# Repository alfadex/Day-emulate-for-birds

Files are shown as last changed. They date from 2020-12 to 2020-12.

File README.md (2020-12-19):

# Day-light-emulate-for-birds

Operation of the project
https://github.com/alfadex/Day-emulate-for-birds/wiki

Ζero cross detection
https://alfadex.com/2014/02/dimming-230v-ac-with-arduino-2/

Bird timer Switch v.1
https://alfadex.com/2015/03/bird-timer-switch/

Bird timer Switch v.2
https://alfadex.com/2015/03/bird-timer-switch-v-2/

Code for this project refer to v.2

video
https://youtu.be/kFFZ-1XAeRA

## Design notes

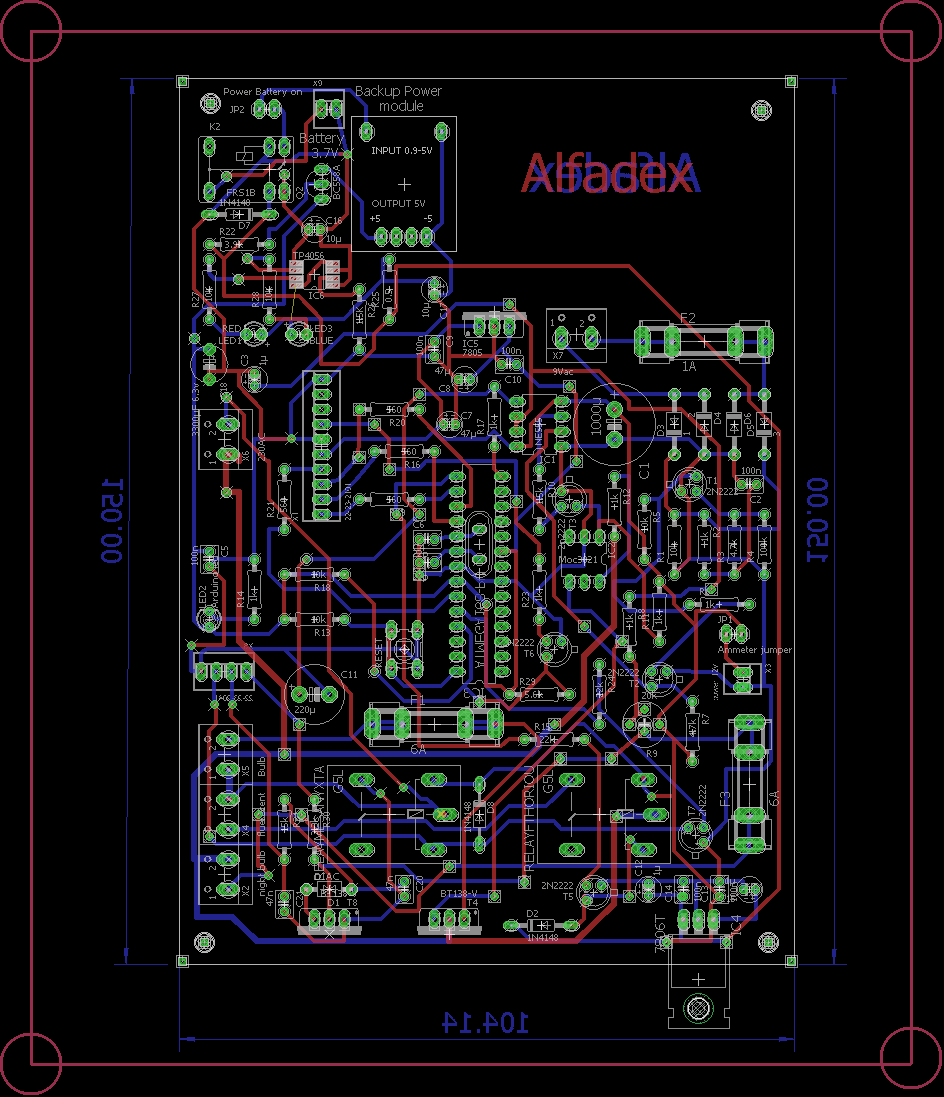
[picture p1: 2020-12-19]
Schematic-board files/Board.png

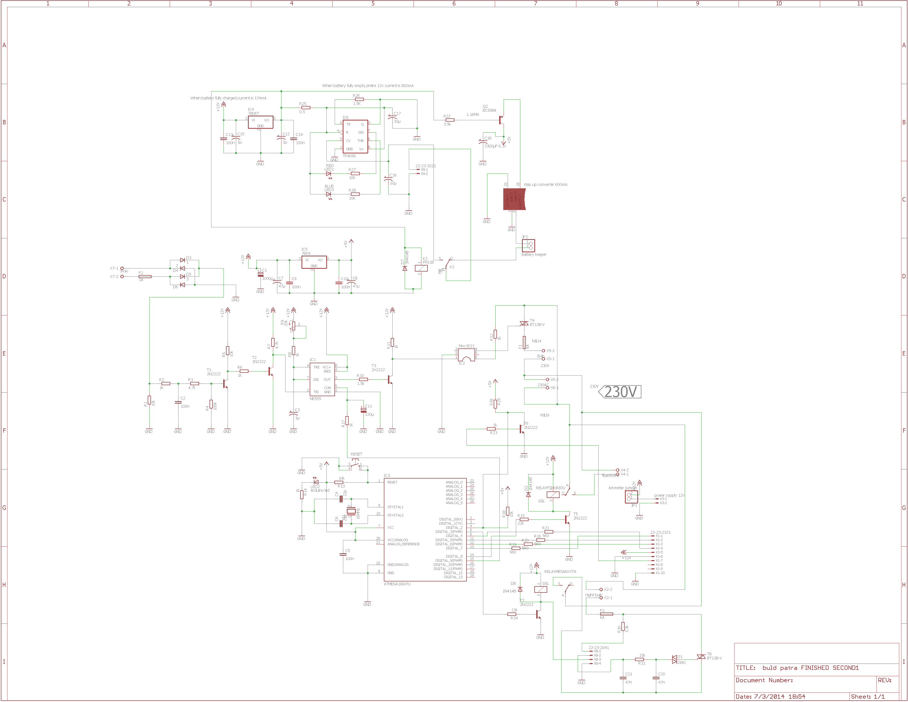
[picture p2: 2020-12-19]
Schematic-board files/schematic.png

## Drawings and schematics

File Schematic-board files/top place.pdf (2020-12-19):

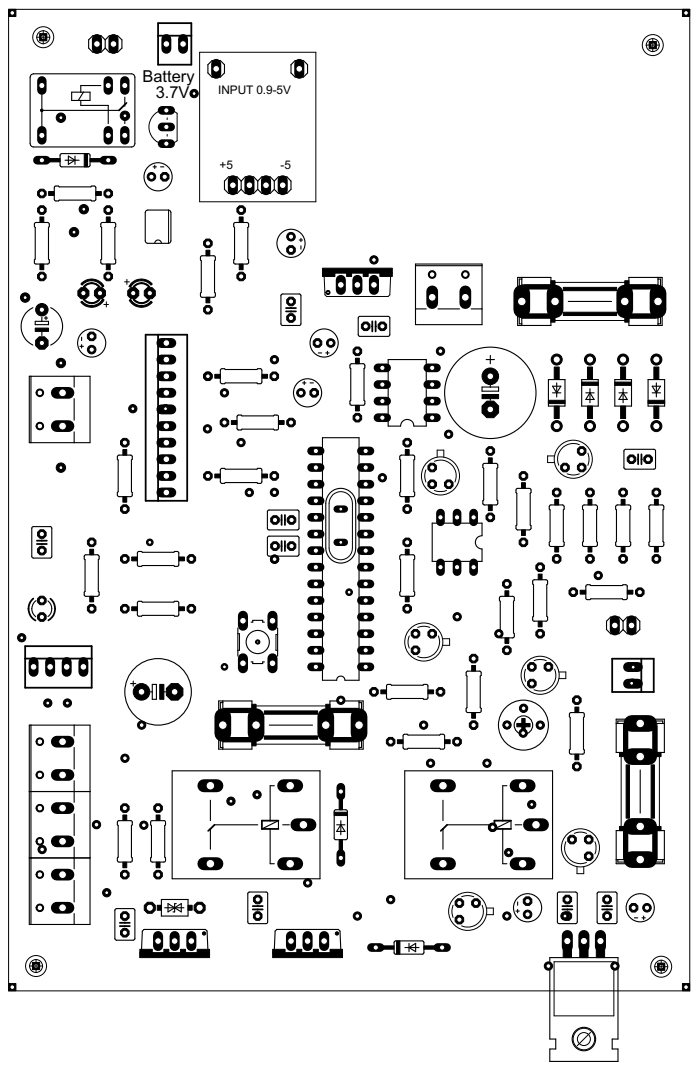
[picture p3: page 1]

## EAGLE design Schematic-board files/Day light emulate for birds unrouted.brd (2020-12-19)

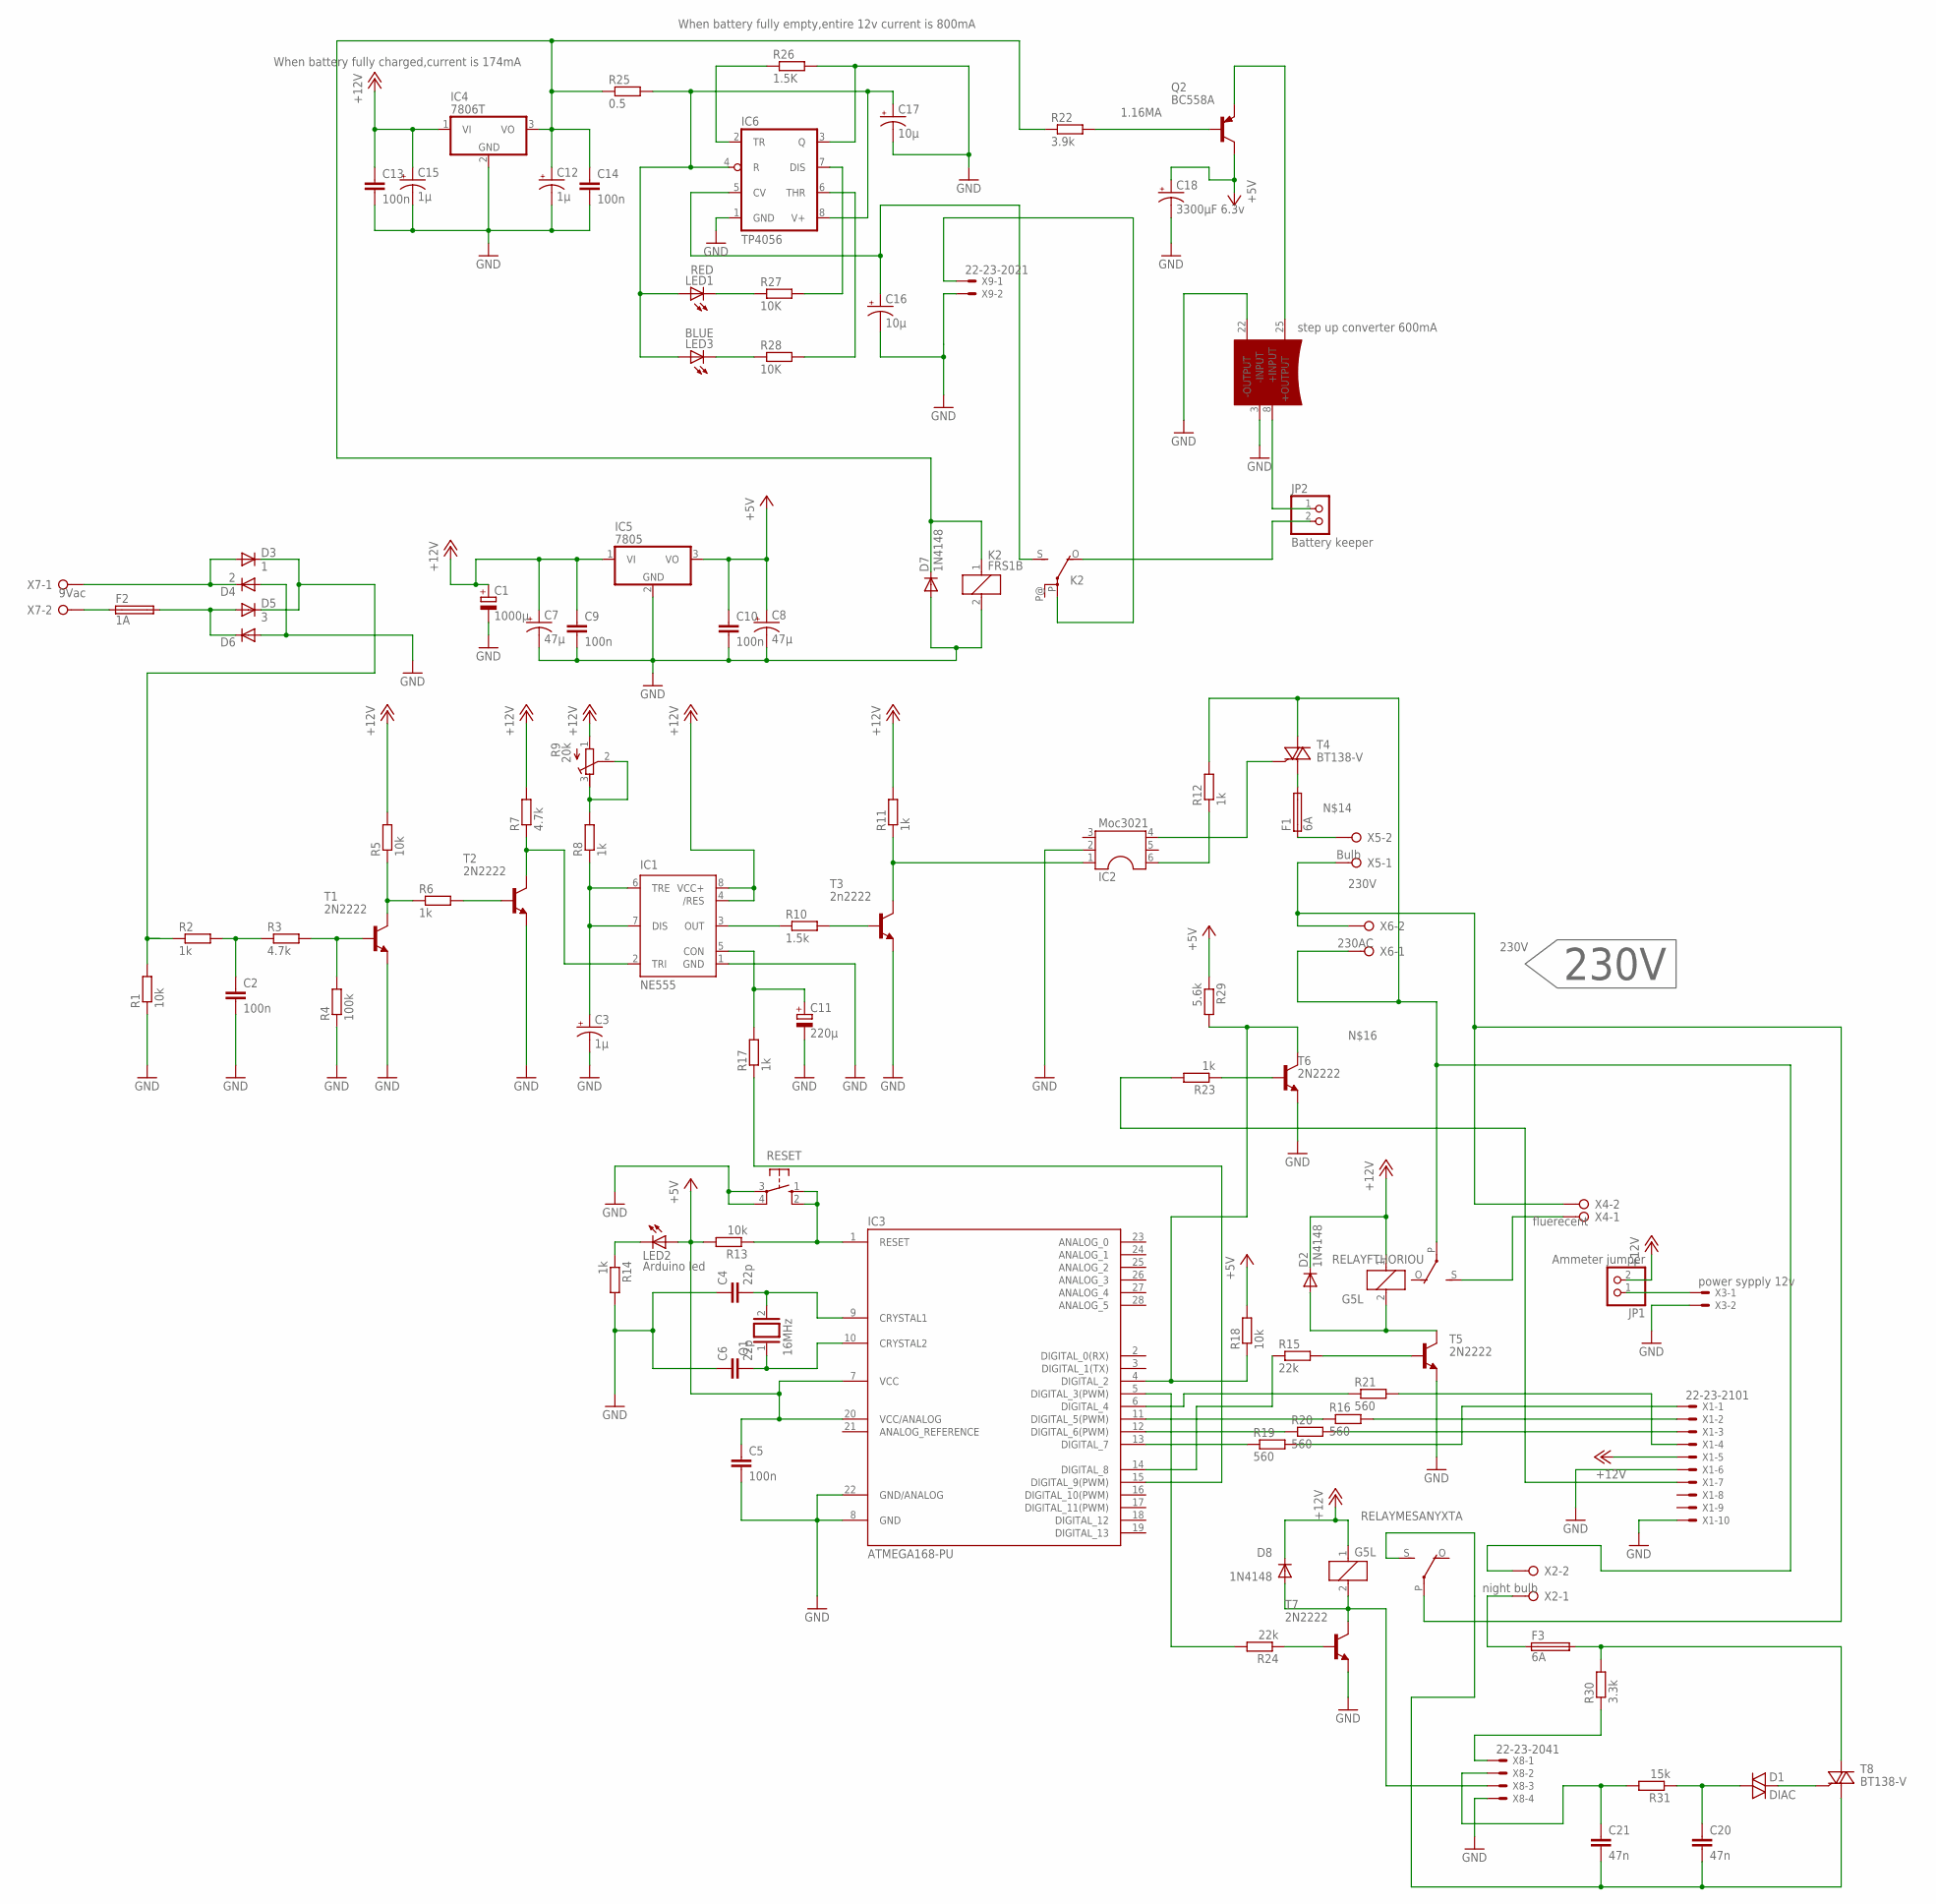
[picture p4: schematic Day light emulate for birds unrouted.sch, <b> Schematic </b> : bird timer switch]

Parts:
C1: 1000μ; E5-13
C2, C5, C9, C10, C13, C14: 100n; C025-030X050
C3, C12, C15: 1μ; E2-4
C4, C6: 22p; C025-030X050
C7, C8: 47μ; E2-4
C11: 220μ; E5-10,5
C16, C17: 10μ; E2-4
C18: 3300μF 6.3v; E5-6
C20, C21: 47n; C025-030X050
D1: DIAC; GT32
D2, D7, D8: 1N4148; DO35-10
D3: 1; DO41-10
D4: 2; DO41-10
D5: 3; DO41-10
D6: 1N4004; DO41-10
F1, F3: 6A; SHK20L
F2: 1A; SHK20L
IC1: NE555; DIL-08
IC2: Moc3021; DIL06
IC3: ATMEGA168-PU; DIL28-3
IC4: 7806T; TO220H
IC5: 7805; TO220V
IC6: TP4056; SO08
JP1: Ammeter jumper; 1X02
JP2: Battery keeper; 1X02
K2: FRS1B
LED1: RED; LED3MM
LED2: Arduino led; LED3MM
LED3: BLUE; LED3MM
Q1: 16MHz; QS
Q2: BC558A; TO92-EBC
R1, R5, R13, R18: 10k; 0207/10
R2, R6, R8, R11, R12, R14, R17, R23: 1k; 0207/10
R3, R7: 4.7k; 0207/10
R4: 100k; 0207/10
R9: 20k; RTRIM3339P
R10: 1.5k; 0207/10
R15, R24: 22k; 0207/10
R16, R19, R20, R21: 560; 0207/10
R22: 3.9k; 0207/10
R25: 0.5; 0207/10
R26: 1.5K; 0207/10
R27, R28: 10K; 0207/10
R29: 5.6k; 0207/10
R30: 3.3k; 0207/10
R31: 15k; 0207/10
RELAYFTHORIOU: G5L; G5LE
RELAYMESANYXTA: G5L; G5LE
RESET: 10-XX; B3F-10XX
STEPUP1: steup converter 600mA; STEPUP_CONVERTER_600MA
T1, T2, T5, T6, T7: 2N2222; TO18
T3: 2n2222; TO18
T4, T8: BT138-V; TO220BV
X1: 22-23-2101
X2: night bulb; W237-132
X3: power sypply 12v; 22-23-2021
X4: fluerecent; W237-132
X5: Bulb; W237-132
X6: 230AC; W237-132
X7: 9Vac; W237-132
X8: 22-23-2041
X9: 22-23-2021

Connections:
1.16MA: Q2.B, R22.2
230V: RELAYMESANYXTA.P, X4.2, X5.1, X6.2
+5V: C5.1, C8.+, C10.1, C18.+, IC3.7 (VCC), IC3.20 (VCC/ANALOG), IC5.3 (VO), LED2.A, Q2.C, R13.2, R18.2, R29.1
+12V: C1.+, C7.+, C9.1, C13.1, C15.+, D2.C, D8.C, IC1.4 (/RES), IC1.8 (VCC+), IC4.1 (VI), IC5.1 (VI), JP1.2, R5.2, R7.2, R9.1 (E), R11.2, RELAYFTHORIOU.1, RELAYMESANYXTA.1, X1.5
GND: C1.-, C2.2, C3.-, C4.1, C5.2, C6.1, C7.-, C8.-, C9.2, C10.2, C11.-, C12.-, C13.2, C14.2, C15.-, C16.-, C17.-, C18.-, D4.A, D6.A, D7.A, IC1.1 (GND), IC2.2, IC3.8 (GND), IC3.22 (GND/ANALOG), IC4.2 (GND), IC5.2 (GND), IC6.1 (GND), IC6.3 (Q), K2.2, R1.1, R4.1, R14.2, R26.2, RESET.3, RESET.4 (P1), STEPUP1.3 (-INPUT), STEPUP1.22 (-OUTPUT), T1.1 (E), T2.1 (E), T3.1 (E), T5.1 (E), T6.1 (E), T7.1 (E), X1.6, X1.10, X3.2, X8.4, X9.2
MORNING: R19.2, X1.1
unnamed: IC3.11 (DIGITAL_5(PWM)), R16.1
unnamed: C2.1, R2.2, R3.1
unnamed: R3.2, R4.2, T1.2 (B)
unnamed: R5.1, R6.1, T1.3 (C)
unnamed: R6.2, T2.2 (B)
unnamed: IC1.2 (TRI), R7.1, T2.3 (C)
unnamed: R8.2, R9.2 (S), R9.3 (A)
unnamed: IC1.3 (OUT), R10.1
unnamed: C3.+, IC1.6 (TRE), IC1.7 (DIS), R8.1
unnamed: R10.2, T3.2 (B)
unnamed: IC2.1, R11.1, T3.3 (C)
unnamed: IC2.6, R12.1
unnamed: IC2.4, T4.G
unnamed: F1.1A (1), X5.2
unnamed: JP2.1, STEPUP1.8 (+INPUT)
unnamed: R12.2, RELAYFTHORIOU.P, T4.T2 (A2), X2.2, X6.1
unnamed: F2.1A (1), X7.2
unnamed: IC3.1 (RESET), R13.1, RESET.1 (S), RESET.2 (S1)
unnamed: LED2.K (C), R14.1
unnamed: D1.2, T8.G
unnamed: C6.2, IC3.10 (CRYSTAL2), Q1.1
unnamed: C4.2, IC3.9 (CRYSTAL1), Q1.2
unnamed: IC3.14 (DIGITAL_8), R15.1
unnamed: R15.2, T5.2 (B)
unnamed: D2.A, RELAYFTHORIOU.2, T5.3 (C)
unnamed: IC3.13 (DIGITAL_7), R19.1
unnamed: C11.+, IC1.5 (CON), R17.2
unnamed: R16.2, X1.2
unnamed: IC3.15 (DIGITAL_9(PWM)), R17.1
unnamed: IC3.6 (DIGITAL_4), R21.1
unnamed: R21.2, X1.4
unnamed: RELAYFTHORIOU.S, X4.1
unnamed: IC3.12 (DIGITAL_6(PWM)), R20.1
unnamed: D3.A, D4.C, X7.1
unnamed: D5.A, D6.C, F2.2A (2)
unnamed: D3.C, D5.C, R1.2, R2.1
unnamed: R20.2, X1.3
unnamed: K2.P, X9.1
unnamed: JP2.2, K2.O
unnamed: C12.+, C14.1, D7.C, IC4.3 (VO), K2.1, R22.1, R25.1
unnamed: IC3.5 (DIGITAL_3(PWM)), R24.2
unnamed: R24.1, T7.2 (B)
unnamed: D8.A, RELAYMESANYXTA.2, T7.3 (C), X8.3
unnamed: C20.2, C21.2, RELAYMESANYXTA.S, T8.T1 (A1)
unnamed: Q2.E, STEPUP1.25 (+OUTPUT)
unnamed: C17.+, IC6.4 (R), IC6.8 (V+), LED1.A, LED3.A, R25.2
unnamed: IC6.7 (DIS), R27.2
unnamed: IC6.6 (THR), R28.2
unnamed: C16.+, IC6.5 (CV), K2.S
unnamed: LED1.K (C), R27.1
unnamed: IC6.2 (TR), R26.1
unnamed: LED3.K (C), R28.1
unnamed: JP1.1, X3.1
unnamed: R23.2, X1.7
unnamed: R23.1, T6.2 (B)
unnamed: IC3.4 (DIGITAL_2), R18.1, R29.2, T6.3 (C)
unnamed: C20.1, D1.1, R31.1
unnamed: C21.1, R31.2, X8.2
unnamed: R30.1, X8.1
unnamed: F3.1A (1), X2.1
unnamed: F3.2A (2), R30.2, T8.T2 (A2)
unnamed: F1.2A (2), T4.T1 (A1)

Board: 2 copper layers, 97 parts (3 on the bottom side), 68 nets, no tracks yet.

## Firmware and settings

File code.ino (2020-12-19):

//                     https://alfadex.com/2015/03/bird-timer-switch-v-2/

const byte ledFade = 9;                   // pin για ρύθμηση φωτεινότητας λάμπας πυρακτώσεως
const byte buttonPin = 2;                 // εντολή απο το μετρητή - ρολοι
int val = 0;                              // variable for reading the pin status
static unsigned int count;                // variable for fading
const byte relayFthoriou = 8;             // ρελές για λαμπα φθορίου
const byte relaynight = 3;                // ρελές για λαμπα μεσάνυχτα
const byte LedMorning = 7;                // led πρωινο
const byte LedDay = 5;                    // led ημέρας για λαμπα φθορίου
const byte Lednyxtoma = 6;                // led όταν βραδιαζει
const byte Lednight = 4;                  // led για μεσάνυχτα
int buttonState = 0;
int timer;

int kshmeroma() {                         // εδω ξεκινάει να αναβει η λάμπα πυρακτώσεως για κάποια λετπά
  digitalWrite(relaynight, LOW);          // σβήνει το relay για τη λάμπα νυκτός
  while (count > 2) {                     // ξεκινάει απο το 255(σβηστή)έως το 2 που είναι τερμα αναμένη
    count--;
    analogWrite(ledFade,        count);
    delay(4900);                          //καθε step απο τα 250,έχει 4,9sec καθυστέρηση 4,9x250=1225sec / 60 = 20.4 λεπτά
    Serial.println(count);
    digitalWrite(LedMorning,    HIGH);    // ανάβει το led morning
    digitalWrite(LedDay,        LOW);     // σβήνει το led day
    digitalWrite(Lednyxtoma,    LOW);     // σβήνει το led nightfall
    digitalWrite(Lednight,      LOW);     // σβήνει το led night
  }
  //εδω έχει περάσει ο χρόνος σβησίματος, οπότε σβήνει η πυρακτώσεως και ανάβει η φθορίου
  analogWrite(ledFade,        255);       // εδώ κρατάω τέρμα σβηστή τη λάμπα πυρακτώσεως
  digitalWrite(LedMorning,    LOW);       // σβήνει το led morning
  digitalWrite(LedDay,        HIGH);      // ανάβει το led day
  digitalWrite(Lednyxtoma,    LOW);       // σβήνει το led nightfall
  digitalWrite(Lednight,      LOW);       // σβήνει το led night
  digitalWrite(relayFthoriou, HIGH);      // ενεργοποιείται το ρελε για τη λαμπα φθορίου
}

int nyxtoma() {                           // εδω ξεκιναει να σβήνει η πυρακτώσεως για καποια λεπτά.Η count είναι 1
  while ( count < 254) {                  // ξεκινάει απο το 1(τέρμα αναμένη) έως το 253 που είναι σβηστή
    count++;
    analogWrite(ledFade,        count);
    delay(4900);                          //καθε step απο τα 250,έχει 4,9sec καθυστέρηση 4,9x250=1225sec / 60 = 20.4 λεπτά
    digitalWrite(relayFthoriou, LOW);     // σβήνει το ρελε για τη λαμπα φθορίου
    digitalWrite(LedDay,        LOW);     // σβήνει το led day
    digitalWrite(Lednyxtoma,    HIGH);    // ανάβει το led nightfall
    Serial.println(count);
  }
  //εδω έχει περάσει ο χρόνος σβησίματος, οπότε σβήνει η πυρακτώσεως και ανάβει το φως νυκτός
  analogWrite(ledFade,          255);     // εδώ κρατάω τέρμα σβηστή τη λάμπα πυρακτώσεως
  digitalWrite(LedMorning,      LOW);     // σβήνει το led morning
  digitalWrite(LedDay,          LOW);     // σβήνει το led day
  digitalWrite(Lednyxtoma,      LOW);     // σβήνει το led nightfall
  digitalWrite(Lednight,        HIGH);    // ανάβει το led night
  digitalWrite(relaynight,      HIGH);    // ενεργοποιείται το ρελε για λάμπα νυκτός
}

void setup() {

  count = 255;                            // μεταβλητή για πυρακτώσεως. 255=σβηστή  0=αναμένη
  Serial.begin(9600);
  pinMode(buttonPin, INPUT);              // διακόπτης απο timer.Όταν ανάβει το led του timer, έχω buttonStatelow αλλιώς high
  pinMode(ledFade, OUTPUT);               // έξοδος που ρυθμήζεις την ένταση της πυρακτώσεως αλλάζοντας τη count
  pinMode(LedMorning, OUTPUT);            // led για ειδοποίηση λάμπας πυρακτώσεως  (morning)
  pinMode(LedDay, OUTPUT);                // led για ειδοποίηση λαμπας φθορίου      (day)
  pinMode(Lednyxtoma, OUTPUT);            // led για ειδοποιήση λάμπας φθορίου      (nightfall)
  pinMode(Lednight, OUTPUT);              // led για ειδοποιήση λάμπας νυκτός       (night)
  pinMode(relayFthoriou, OUTPUT);         // ρελές για να ανάψει η λάμπα φθορίου
  pinMode(relaynight, OUTPUT);            // ρελές για να ανάψει το λαμπάκι νυκτός

                                          // αρχικοποίηση όλα σε LOW
  digitalWrite(ledFade, LOW);      
  digitalWrite(relayFthoriou, LOW);   
  digitalWrite(relaynight, LOW);
  digitalWrite(LedMorning, LOW);
  digitalWrite(Lednyxtoma, LOW);
  digitalWrite(LedDay, LOW);
  analogWrite(ledFade, count);
}

void  loop() {
  buttonState = digitalRead(buttonPin);
  //  if (buttonState != lastButtonState) {

  if (buttonState == HIGH) {
    nyxtoma();
    //Serial.println("buttonStatehigh");
  } else {
    //Serial.println("buttonStatelow");
    kshmeroma();
  }
}
